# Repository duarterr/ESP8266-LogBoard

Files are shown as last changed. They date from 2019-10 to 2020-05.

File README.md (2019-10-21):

# ESP8266 LogBoard

A development platform for the ESP8266 with data logger capabilities. Fully compatible with the Arduino IDE.

<p align="center">
ESP8266 LogBoard
</p>

Author: Renan R. Duarte - <duarte.renan@hotmail.com>

## Features
 - **ESP8266 (ESP12E) microcontroller:** The board is based on the ESP12E module, featuring the ESP8266 microcontroller. The module is configured in DIO SPI mode, so two extras GPIO pins can be used by the application (13 GPIOs in total).
 - **MicroSD card:** Data can be easily stored in a standard microSD card.
 - **Temperature sensor:** The Maxim DS1722 SPI temperature sensor can be used to measure the temperature.
 - **Real-time clock:** A Maxim DS1391 battery-backed SPI real-time clock provides timing capabilities without needing the internet.
 - **Onboard battery charger:** The board can be powered directly from the USB port or by a lithium battery. The onboard battery charger can be configured to fully charge the battery (4.2V) for cyclic use or float charge with a lower voltage (4.1V) to extend battery life in applications where the USB power is always connected.
 - **Switched-mode power supply:** A Maxim MAX8625 buck-boost controller IC provides a high efficiency continuous 3.3V bus to the system.
 - **Onboard programmer:** The device can be programmed directly by the USB port using the onboard USB-Serial bridge (FTDI FT232RQ). This device also enables serial communications between the microcontroller and a PC.

## Repository Contents

* **/Hardware** - PCB related files (EAGLE v9.5.5 and Sketchup 2018).
* **/Firmware** - Arduino example sketches to make use of it. 
* **/Extras** - Images and other stuff. 

## License Information

All contents of this repository are released under [Creative Commons Share-alike 4.0](http://creativecommons.org/licenses/by-sa/4.0/).

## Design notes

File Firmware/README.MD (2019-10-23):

# Firmware

## Arduino/LogBoard
This is the main firmware of the LogBoard.

## Arduino/SD Card files
- **NewSettings_Example.txt:** At boot, the device checks if a "NewSettings.txt" file is present. If it is, all settings in EEPROM are replaced by the ones in this file. "NewSettings_Example.txt" is a template of the configuration file.
- **NewFirmware.bin:** At boot, the device checks if a "NewFirmware.bin" file is present. If it is, the firmware is updated.

## Google Script/GScriptCode.txt
This code gets the logged data via HTTP post and saves it to a Google Sheets document

## Google Script/HTTPsRedirect.php
This code receives the ESP8266 HTTP post requests and redirects the requests to via HTTPS. The URL of this script is the WifiRedirectURL in the Arduino code.

## Firmware Flowchart

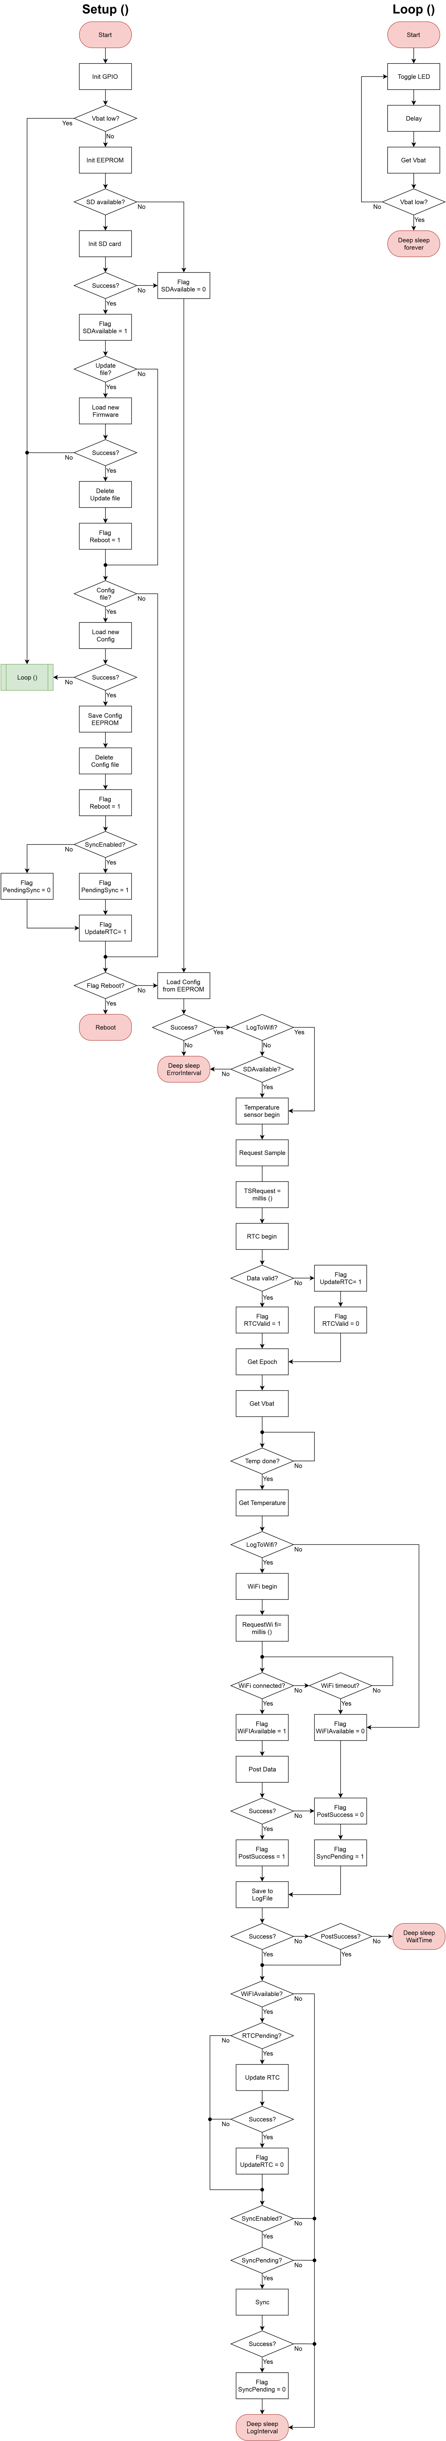
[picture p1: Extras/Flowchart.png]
v1


## License Information

All contents of this repository are released under [Creative Commons Share-alike 4.0](http://creativecommons.org/licenses/by-sa/4.0/).

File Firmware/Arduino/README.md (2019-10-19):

# Arduino sketches and related files

## LogBoard
This is the main firmware of the LogBoard.

## SD Card files
- **NewConfig_Example.txt:** At boot, the device checks if a "NewConfig.txt" file is present. If it is, all settings in EEPROM are replaced by the ones in this file. "NewConfig_Example.txt" is a template of the configuration file.
- **NewFirmware.bin:** At boot, the device checks if a "NewFirmware.bin" file is present. If it is, the firmware is updated.

## License Information

All contents of this repository are released under [Creative Commons Share-alike 4.0](http://creativecommons.org/licenses/by-sa/4.0/).

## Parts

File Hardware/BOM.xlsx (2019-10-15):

Part | Value | Description | Package
C1 | 100n/10V | 0603 SMD capacitor | 0603
C2 | 47u/6.3V | CT3528 SMD tantalum capacitor | CT3528
C3 | 47u/6.3V | CT3528 SMD tantalum capacitor | CT3528
C4 | 1u/10V | 0603 SMD capacitor | 0603
C5 | 1u/10V | 0603 SMD capacitor | 0603
C6 | 0.33F/5.5V - KR-5R5V334-R | Coin cell supercapacitor | PTH 5X11.5
C7 | 10u/10V | 0603 SMD capacitor | 0603
C8 | 100n/10V | 0603 SMD capacitor | 0603
C9 | 100n/10V | 0603 SMD capacitor | 0603
C10 | 100n/10V | 0603 SMD capacitor | 0603
C11 | 1u/10V | 0603 SMD capacitor | 0603
C12 | 100n/10V | 0603 SMD capacitor | 0603
C13 | 100n/10V | 0603 SMD capacitor | 0603
C14 | 100n/10V | 0603 SMD capacitor | 0603
C15 | 10u/10V | 0603 SMD capacitor | 0603
C16 | 100n/10V | 0603 SMD capacitor | 0603
FB1 | 15 | 0603 SMD ferrite bead | 0603
IC1 | ESP12E | ESP12E module | IC-ESP8266-12E
IC2 | FT232RQ | USB UART IC | QFN32
IC3 | MAX14591ETA+ | Logic level translator | TDFN8
IC4 | MAX14591ETA+ | Logic level translator | TDFN8
IC5 | MAX1811ESA+ | USB-Powered Li+ Charger | SO8
IC6 | MAX8625AETD+ | Step-Up/Down DC-DC Converter | TDFN14
IC7 | DS1391U-33+ | Low-Voltage SPI/3-Wire RTCs with Trickle Charger | USOP10
IC8 | DS1722S+ | Digital Thermometer with SPI/3-Wire Interface | SO8
J1 | C77238 | Micro USB 5P B SMD | Micro USB 5P B SMD
J2 | THD2528-11SD-GF | Micro SD card SMD connector | Micro SD card SMD connector
J3 | HEADER 2x9 180 | 09x2 0.1" pitch male header | 09x2 0.1" pitch male header
L1 | SRN3015-3R3M | 3x3mm SMD inductor | 3x3mm SMD inductor
LED1 | BLUE | 0603 SMD LED | 0603
LED2 | RED | 0603 SMD LED | 0603
LED3 | RED | 0603 SMD LED | 0603
LED4 | BLUE | 0603 SMD LED | 0603
Q1 | BC847BS-7-F | Dual NPN transistor | SOT363
R1 | 10k | 0603 SMD resistor | 0603
R2 | 0/WAKE | 0603 SMD resistor | 0603
R3 | 390k | 0603 SMD resistor | 0603
R4 | 100k | 0603 SMD resistor | 0603
R5 | 10k | 0603 SMD resistor | 0603
R6 | 10k | 0603 SMD resistor | 0603
R7 | 10k | 0603 SMD resistor | 0603
R8 | 10k | 0603 SMD resistor | 0603
R9 | 10k | 0603 SMD resistor | 0603
R10 | 33 | 0603 SMD resistor | 0603
R11 | 33 | 0603 SMD resistor | 0603
R12 | 1k | 0603 SMD resistor | 0603
R13 | 1k | 0603 SMD resistor | 0603
S1 | SK-3296S-01-L1 | Right angle SMD slide switch | Right angle SMD slide switch
S2 | TS24CA | Right angle SMD momentary switch | Right angle SMD momentary switch
X1 | SSP-T7-F 32.768kHz 20PPM7pF | 7015 SMD crystal oscillator | 7015 4P

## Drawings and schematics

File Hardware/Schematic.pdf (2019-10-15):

### ABCD

### ABCD

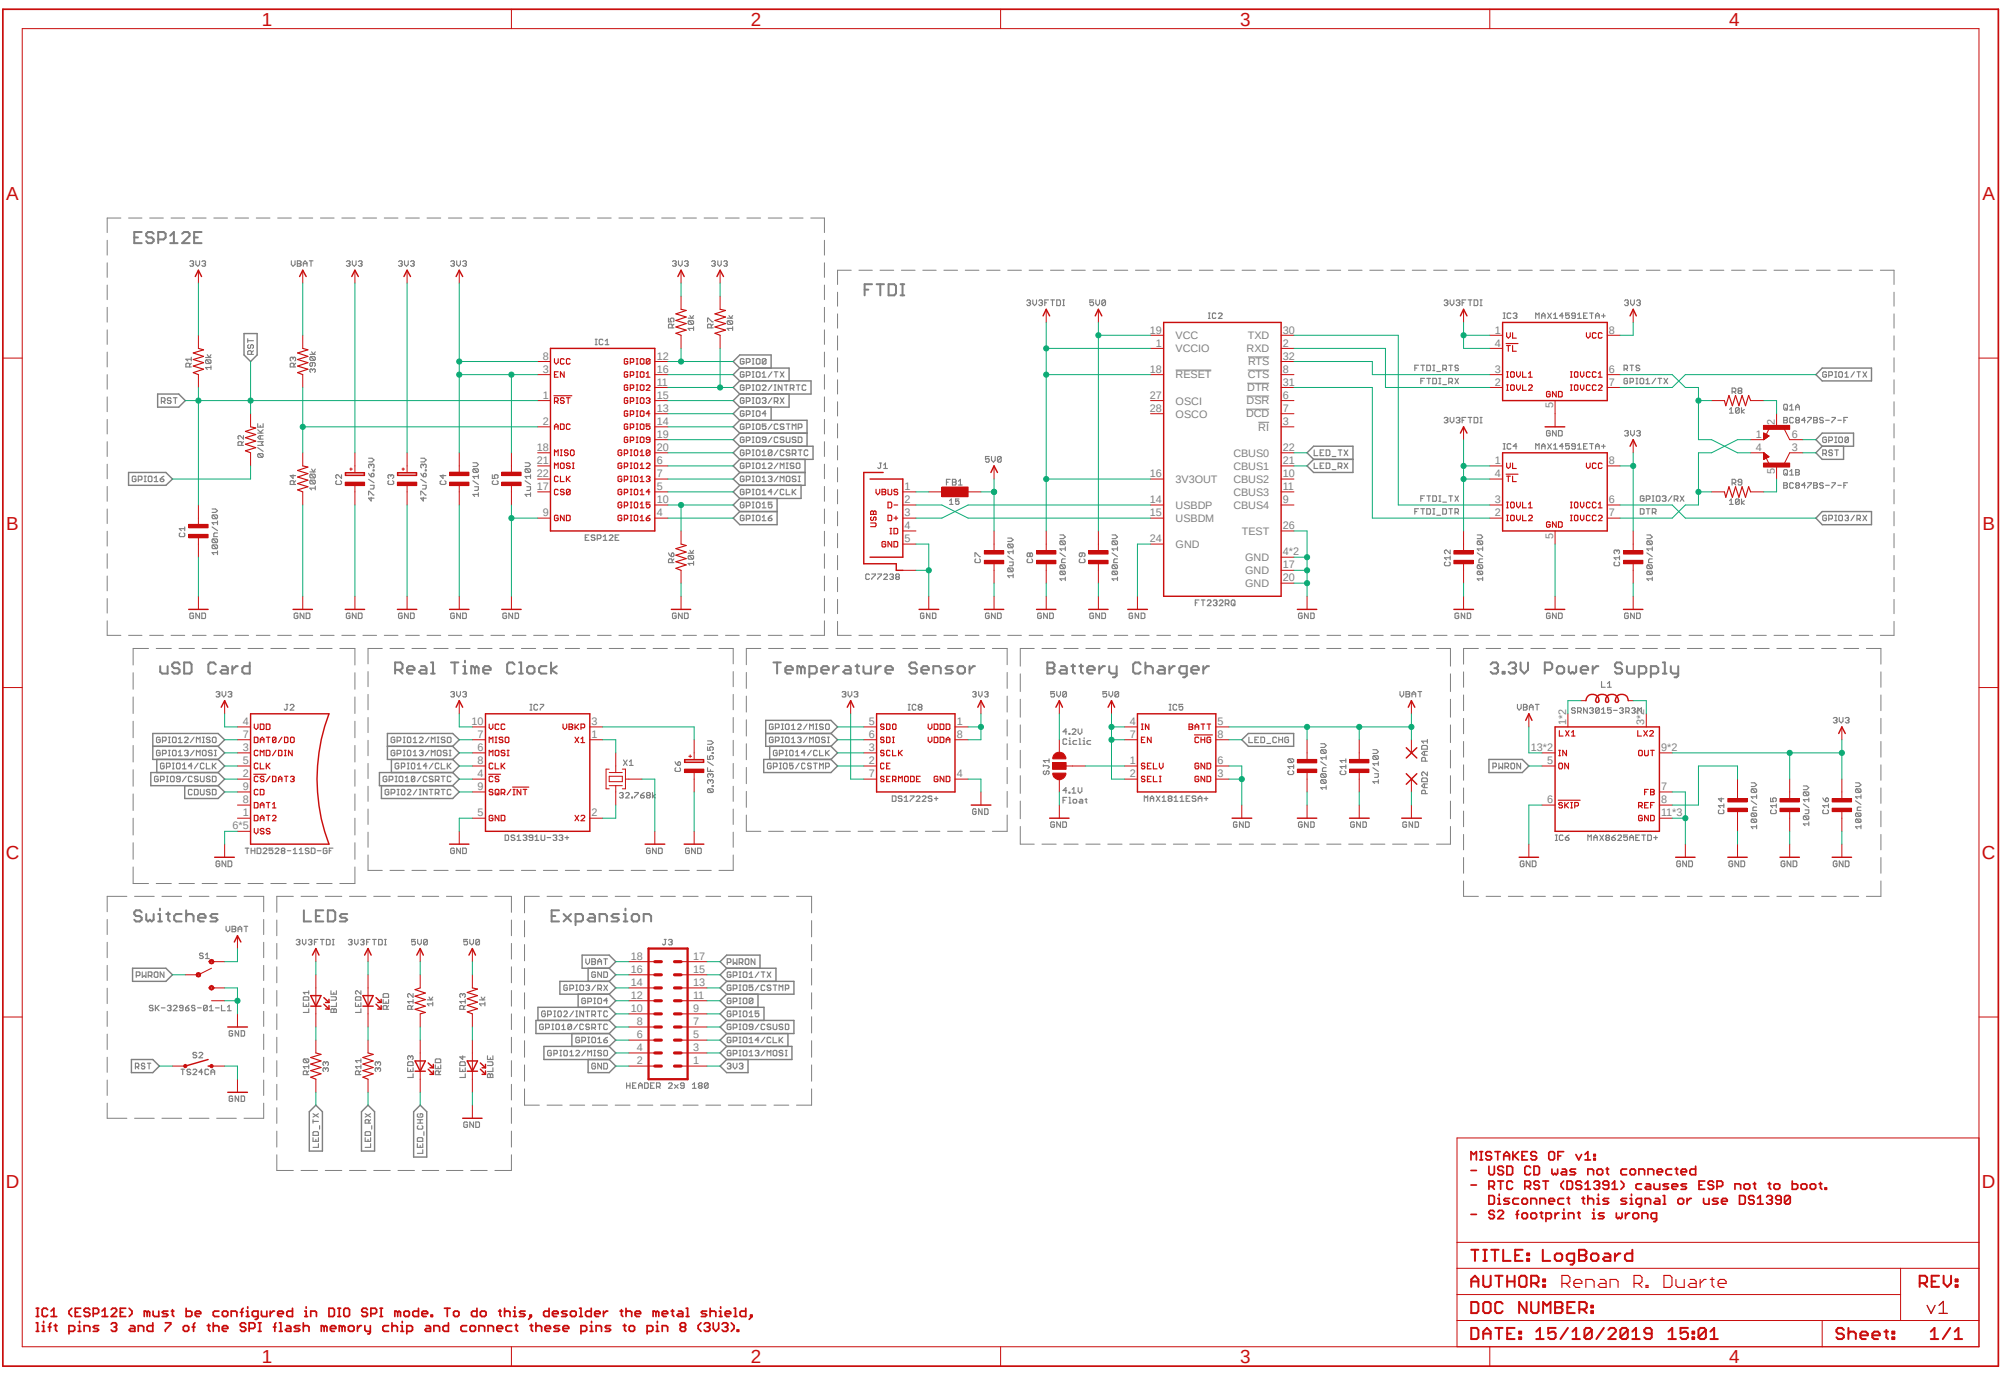
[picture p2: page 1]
CTS; DCD; 7 DSR; 6 DTR; 31 RESET 18; RTS; 3V3OUT 16; CBUS0; CBUS1; CBUS2; CBUS3; CBUS4; GND; GND 24; OSCI 27 OSCO 28; RXD; TEST; TXD; USBDM 15; USBDP 14; VCC 19; VCCIO

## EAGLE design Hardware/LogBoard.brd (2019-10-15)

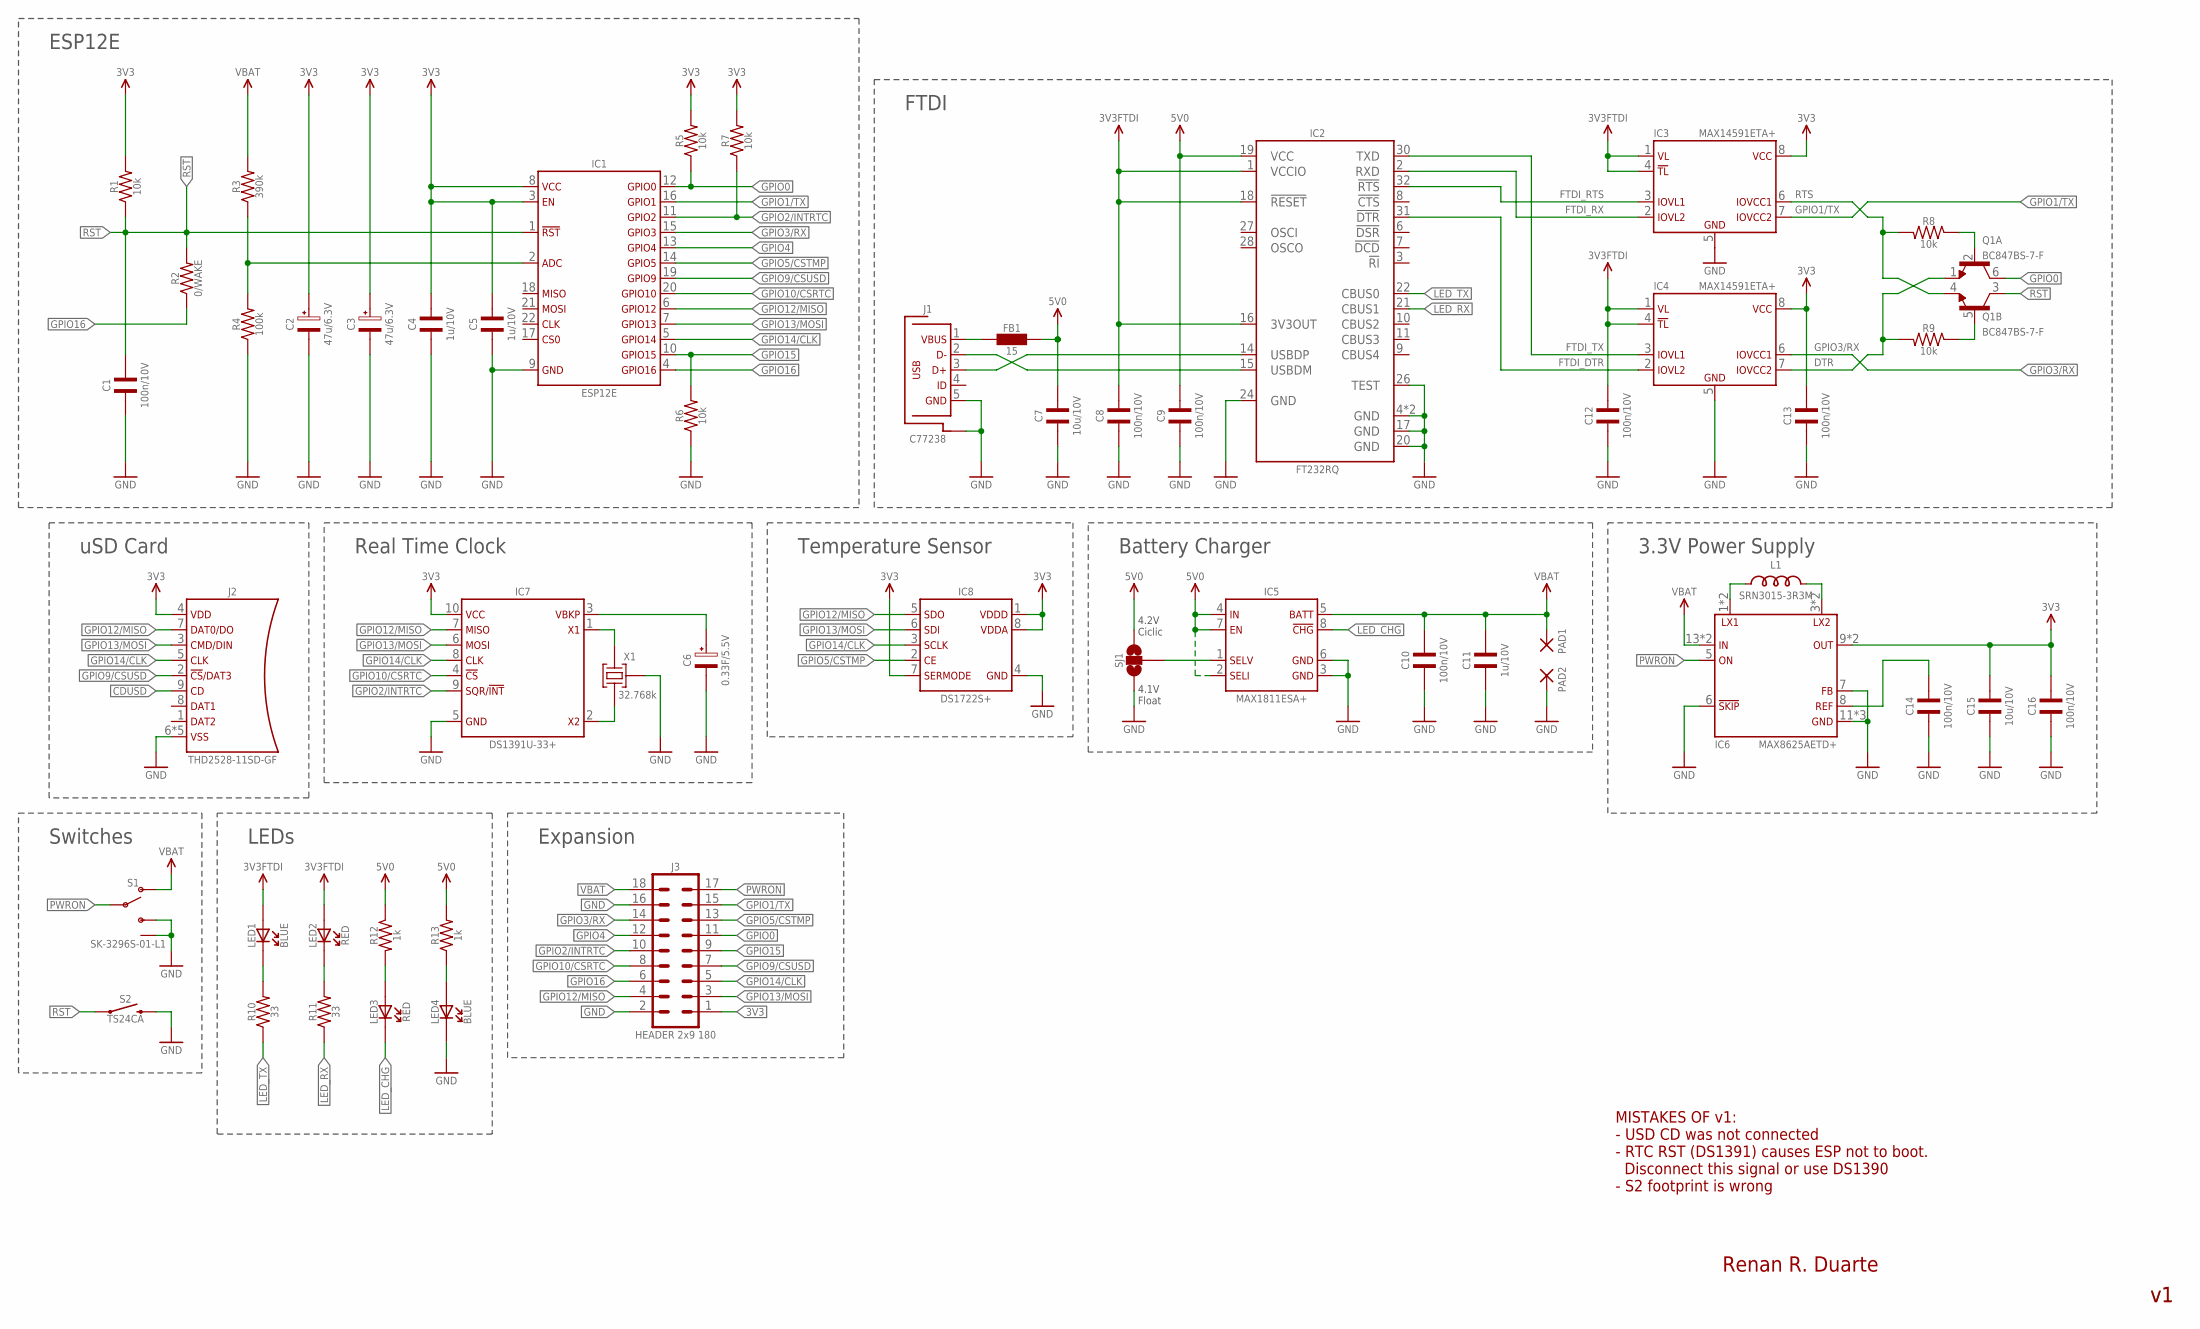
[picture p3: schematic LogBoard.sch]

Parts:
C1, C8, C9, C10, C12, C13, C14, C16: 100n/10V; C-SMD-0603
C2, C3: 47u/6.3V; C-SMD-CT3528
C4, C5, C11: 1u/10V; C-SMD-0603
C6: 0.33F/5.5V; C-PTH-5X11.5
C7, C15: 10u/10V; C-SMD-0603
FB1: 15; R-SMD-0603
IC1: ESP12E; IC-ESP8266-12E
IC2: FT232RQ; IC-QFN32
IC3, IC4: MAX14591ETA+; IC-TDFN8
IC5: MAX1811ESA+; IC-SO8
IC6: MAX8625AETD+; IC-TDFN14
IC7: DS1391U-33+; IC-USOP10
IC8: DS1722S+; IC-SO8
J1: C77238; CN-MICRO-USB
J2: THD2528-11SD-GF; CN-MICROSD
J3: HEADER 2x9 180; PH-9X2-180
L1: SRN3015-3R3M; L-SMD-3X3
LED1, LED4: BLUE; LED-SMD-0603
LED2, LED3: RED; LED-SMD-0603
PAD1, PAD2: SMD2; SMD1,27-2,54
Q1: BC847BS-7-F; IC-SOT363
R1, R5, R6, R7, R8, R9: 10k; R-SMD-0603
R2: 0/WAKE; R-SMD-0603
R3: 390k; R-SMD-0603
R4: 100k; R-SMD-0603
R10, R11: 33; R-SMD-0603
R12, R13: 1k; R-SMD-0603
S1: SK-3296S-01-L1; SWITCH_SPST_SMD_A
S2: TS24CA; TACTILE_SWITCH_SMD_RIGHT_ANGLE
SJ1: SJ-3
X1: 32.768k; CRYSTAL-SMD-7X1.5

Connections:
3V3: C2.+, C3.+, C4.P$1 (1), C5.P$1 (1), C13.P$2 (2), C15.P$1 (1), C16.P$1 (1), IC1.3 (EN), IC1.8 (VCC), IC3.8 (VCC), IC4.8 (VCC), IC6.9 (OUT), IC6.10 (OUT), IC7.10 (VCC), IC8.1 (VDDD), IC8.7 (SERMODE), IC8.8 (VDDA), J2.4 (VDD), J3.1, R1.P$2 (2), R5.P$2 (2), R7.P$2 (2)
3V3FTDI: C8.P$2 (2), C12.P$2 (2), IC2.1 (VCCIO), IC2.16 (3V3OUT), IC2.18 (!RESET), IC3.1 (VL), IC3.4 (!TL), IC4.1 (VL), IC4.4 (!TL), LED1.A, LED2.A
5V0: C7.P$2 (2), C9.P$2 (2), FB1.P$2 (2), IC2.19 (VCC), IC5.2 (SELI), IC5.4 (IN), IC5.7 (EN), R12.P$1 (1), R13.P$2 (2), SJ1.1
CDUSD: J2.9 (CD)
DTR: IC4.7 (IOVCC2), Q1.1 (E), R9.P$2 (2)
FTDI_DTR: IC2.31 (!DTR), IC4.2 (IOVL2)
FTDI_RTS: IC2.32 (!RTS), IC3.3 (IOVL1)
FTDI_RX: IC2.2 (RXD), IC3.2 (IOVL2)
FTDI_TX: IC2.30 (TXD), IC4.3 (IOVL1)
GND: C1.P$1 (1), C2.- (N), C3.- (N), C4.P$2 (2), C5.P$2 (2), C6.N, C7.P$1 (1), C8.P$1 (1), C9.P$1 (1), C10.P$2 (2), C11.P$2 (2), C12.P$1 (1), C13.P$1 (1), C14.P$2 (2), C15.P$2 (2), C16.P$2 (2), IC1.9 (GND), IC2.4 (GND), IC2.17 (GND), IC2.20 (GND), IC2.24 (GND), IC2.26 (TEST), IC2.GND, IC3.5 (GND), IC4.5 (GND), IC5.3 (GND), IC5.6 (GND), IC6.6 (!SKIP), IC6.7 (FB), IC6.11 (GND), IC6.12 (GND), IC6.TP (GND), IC7.5 (GND), IC8.4 (GND), J1.5 (GND), J1.SHELL (SHIELD), J1.SHELL1 (SHIELD), J1.SHELL2 (SHIELD), J1.SHELL3 (SHIELD), J2.6 (VSS), J2.G1 (VSS), J2.G2 (VSS), J2.G3 (VSS), J2.G4 (VSS), J3.2, J3.16, LED4.C, PAD2.1, R4.P$1 (1), R6.P$1 (1), S1.3 (S), S1.GND1, S1.GND2, S1.GND3, S1.GND4, S2.2, SJ1.3, X1.3 (2), X1.4 (2)
GPIO0: IC1.12 (GPIO0), J3.11, Q1.6 (C), R5.P$1 (1)
GPIO1/TX: IC1.16 (GPIO1), IC3.7 (IOVCC2), J3.15
GPIO2/INTRTC: IC1.11 (GPIO2), IC7.9 (INT), J3.10, R7.P$1 (1)
GPIO3/RX: IC1.15 (GPIO3), IC4.6 (IOVCC1), J3.14
GPIO4: IC1.13 (GPIO4), J3.12
GPIO5/CSTMP: IC1.14 (GPIO5), IC8.2 (CE), J3.13
GPIO9/CSUSD: IC1.19 (GPIO9), J2.2 (CD_DAT3_CS), J3.7
GPIO10/CSRTC: IC1.20 (GPIO10), IC7.4 (CS), J3.8
GPIO12/MISO: IC1.6 (GPIO12), IC7.7 (MISO), IC8.5 (SDO), J2.7 (DAT0_DO), J3.4
GPIO13/MOSI: IC1.7 (GPIO13), IC7.6 (MOSI), IC8.6 (SDI), J2.3 (CMD_DIN), J3.3
GPIO14/CLK: IC1.5 (GPIO14), IC7.8 (CLK), IC8.3 (SCLK), J2.5 (CLK), J3.5
GPIO15: IC1.10 (GPIO15), J3.9, R6.P$2 (2)
GPIO16: IC1.4 (GPIO16), J3.6, R2.P$1 (1)
LED_CHG: IC5.8 (!CHG), LED3.C
LED_RX: IC2.21 (CBUS1), R11.P$1 (1)
LED_TX: IC2.22 (CBUS0), R10.P$1 (1)
unnamed: Q1.2 (B), R8.P$1 (1)
unnamed: Q1.5 (B), R9.P$1 (1)
unnamed: FB1.P$1 (1), J1.1 (VBUS)
unnamed: IC2.15 (USBDM), J1.2 (D-)
unnamed: IC2.14 (USBDP), J1.3 (D+)
unnamed: LED1.C, R10.P$2 (2)
unnamed: LED2.C, R11.P$2 (2)
unnamed: LED3.A, R12.P$2 (2)
unnamed: IC5.1 (SELV), SJ1.2
unnamed: IC6.1 (LX1), IC6.2 (LX1), L1.P$1 (1)
unnamed: IC6.3 (LX2), IC6.4 (LX2), L1.P$2 (2)
unnamed: IC1.2 (ADC), R3.P$1 (1), R4.P$2 (2)
unnamed: IC7.1 (X1), X1.2 (3)
unnamed: IC7.2 (X2), X1.1
unnamed: C14.P$1 (1), IC6.8 (REF)
unnamed: LED4.A, R13.P$1 (1)
PWRON: IC6.5 (ON), J3.17, S1.2
RST: C1.P$2 (2), IC1.1 (RST), Q1.3 (C), R1.P$1 (1), R2.P$2 (2), S2.1
RTS: IC3.6 (IOVCC1), Q1.4 (E), R8.P$2 (2)
VBAT: C10.P$1 (1), C11.P$1 (1), IC5.5 (BATT), IC6.13 (IN), IC6.14 (IN), J3.18, PAD1.1, R3.P$2 (2), S1.1 (O)
VBKP: C6.P, IC7.3 (VBKP)

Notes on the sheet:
4.1V Float
4.2V Ciclic
FTDI
Battery Charger
3.3V Power Supply
ESP12E
Expansion
uSD Card
Real Time Clock
LEDs
Switches
Temperature Sensor
MISTAKES OF v1: - USD CD was not connected - RTC RST (DS1391) causes ESP not to boot. Disconnect this signal or use DS1390 - S2 footprint is wrong
Renan R. Duarte

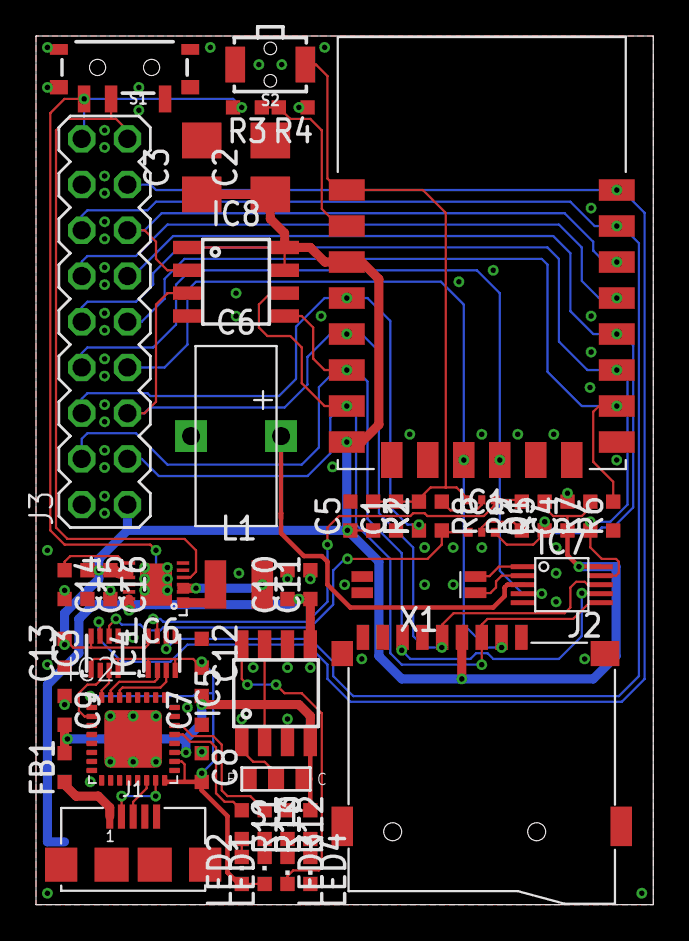
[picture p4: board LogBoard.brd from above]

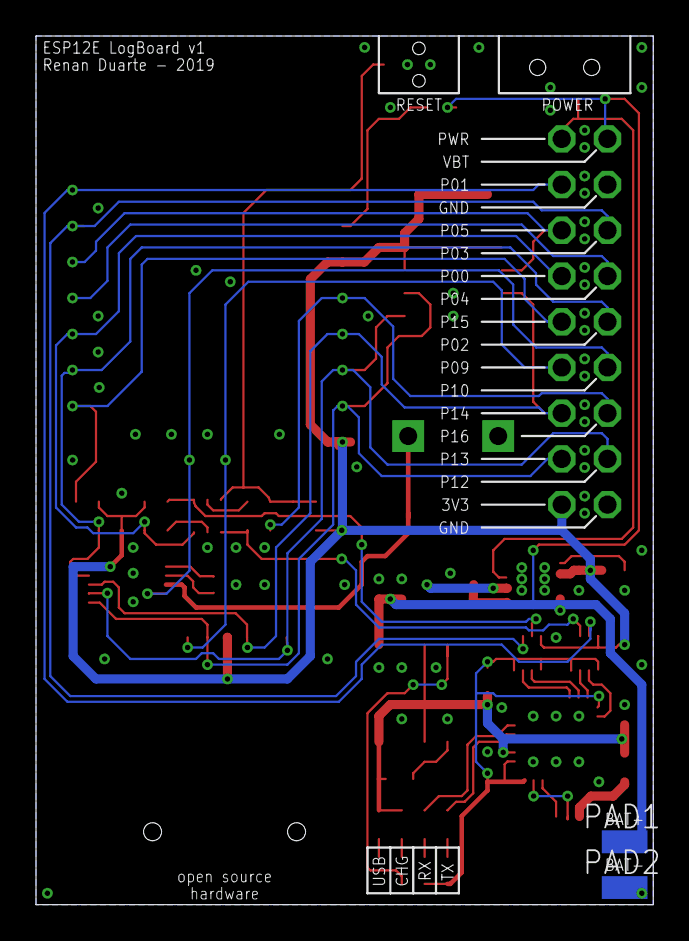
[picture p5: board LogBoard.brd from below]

Board: 2 copper layers, 34.3 x 48.3 mm, 54 parts (3 on the bottom side), 46 nets.

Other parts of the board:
U$7: OSHW_5MM

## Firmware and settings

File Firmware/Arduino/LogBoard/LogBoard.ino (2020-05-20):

/* ------------------------------------------------------------------------------------------- */
// LogBoard - Data logger firwmare for the ESP8266 LogBoard
// Version: 1.2
// Author:  Renan R. Duarte
// E-mail:  duarte.renan@hotmail.com
// Date:    May 19, 2020
//
// Notes:   Sending data to Google Sheets (via Google Script) could be done directly using the
//          WiFiClientSecure library. However, HTTPS requests require more heap memory than
//          the device has available in this code when the HTTPS connection is made.
//          As a solution, this code sends an HTTP request to a server where a HTTPs redirect
//          is performed using cURL.
//
// TODO: 	If log file is large, sync may take a lot of time. Must find a way to keep
//          track of where to start the sync.
//			
//
// Released into the public domain
/* ------------------------------------------------------------------------------------------- */

/* ------------------------------------------------------------------------------------------- */
// Libraries
/* ------------------------------------------------------------------------------------------- */

// DS1722 SPI thermometer related functions
#include <DS1722_SPI.h> // https://github.com/duarterr/Arduino-DS1722-SPI

// DS1390 SPI real time clock related functions
#include <DS1390_SPI.h> // https://github.com/duarterr/Arduino-DS1390-SPI

// ESP8266 WiFi related functions
#include <ESP8266WiFi.h>

// ESP8266 HTTP client related functions
#include <ESP8266HTTPClient.h>

// ESP8266 UDP related functions
#include <WiFiUdp.h>

// NTP client related functions
#include <NTPClient.h>

// EEPROM module related functions
#include <EEPROM.h>

// SD card related functions
#include <SdFat.h>
using namespace sdfat;

// BME280 related functions
#include <Adafruit_Sensor.h>
#include <Adafruit_BME280.h>

/* ------------------------------------------------------------------------------------------- */
// Hardware defines
/* ------------------------------------------------------------------------------------------- */

// Peripheral pins
#define PIN_SD_CS               9
#define PIN_SD_CD               4
#define PIN_RTC_CS              10
#define PIN_TS_CS               5
#define PIN_BME_CS              15
#define PIN_LED                 2
#define PIN_ADC                 A0

// ADC gain
#define ADC_GAIN                0.005343342

/* ------------------------------------------------------------------------------------------- */
// Software default constants
/* ------------------------------------------------------------------------------------------- */

// Default settings filename
const PROGMEM char* FilenameNewSettings = "NewSettings.txt";

// Default firmware filename
const PROGMEM char* FilenameNewFirmware = "NewFirmware.bin";

// NTP server - Result is given by server closest to you, so it's usually in your timezone
const PROGMEM char* NTPServerURL = "0.br.pool.ntp.org";  // Brazilian server

/* ------------------------------------------------------------------------------------------- */
// Software defines
/* ------------------------------------------------------------------------------------------- */

// Code debug with serial port
#define DEBUG_SERIAL            true

// Time to sleep if an error occur loading settings from EEPROM (seconds)
#define ERROR_SLEEP_INTERVAL    60

// WiFi connection timeout (milliseconds)
#define WIFI_TIMEOUT            5000

// Battery voltage cutoff voltage (volts)
#define VBAT_LOW                3

// EEPROM addresses
#define ADDR_LOG_FILENAME       0x000 // 64 bytes (63c + '\n')
#define ADDR_LOG_INTERVAL       0x040 // 2 bytes (MSB + LSB)
#define ADDR_LOG_WAIT_TIME      0x042 // 2 bytes (MSB + LSB) 
#define ADDR_LOG_TIMEZONE       0x044 // 2 bytes (MSB + LSB)
#define ADDR_WIFI_ENABLED       0x046 // 1 byte
#define ADDR_WIFI_SYNC          0x047 // 1 byte
#define ADDR_WIFI_SSID          0x048 // 32 bytes (31c + '\n')
#define ADDR_WIFI_PSW           0x068 // 32 bytes (31c + '\n')
#define ADDR_WIFI_REDIRECTURL   0x088 // 64 bytes (63c + '\n')
#define ADDR_WIFI_GSCRIPTURL    0x0C8 // 128 bytes (127c + '\n')
#define ADDR_CHECKSUM           0x148 // 4 bytes
#define ADDR_RTC_PENDING        0x14C // 1 byte
#define ADDR_SYNC_PENDING       0x14D // 1 byte

// EEPROM total bytes
#define EEPROM_SIZE             0x14E // 334 bytes

/* ------------------------------------------------------------------------------------------- */
// Global variables
/* ------------------------------------------------------------------------------------------- */

// Configuration variables
struct StructSettings
{
  char LogFilename[64] = {0};         // SD card log file       
  unsigned int LogInterval = 1;       // Time between samples (10 to 3600 seconds)
  unsigned int LogWaitTime = 1;       // Time to wait after on error (1 to 3600 seconds)
  int LogTimezone = 0;                // Timezone (-12 to +12, 0 = GMT)
  unsigned char WifiEnabled = 0;      // Use WiFi functions
  unsigned char WifiSyncEnable = 0;   // Sync data stored in SD card to Google Sheets
  char WifiSSID[32] = {0};            // WiFi SSID
  char WifiPsw[32] = {0};             // WiFi password
  char WifiRedirectURL[64] = {0};     // URL of the HTTP->HTTPs redirect host
  char WifiGScriptURL[128] = {0};     // Google Script ID
} Settings, NewSettings;

// Sampled data
struct StructSample
{
  unsigned char DeviceMAC[6] = {};    // Device MAC address
  float Temperature = 0;              // DS1722 temperature
  float BatteryVoltage = 0;           // ADC voltage
  unsigned long RTCEpoch = 0;         // RTC date and time - Epoch format
  bool RTCValid = false;              // RTC memory was not lost. Data is reliable
  bool BmeStatus = false;             // BME280 status
  float BmeTemperature = 0;           // BME280 temperature
  float BmePressure = 0;              // BME280 pressure
  float BmeHumidity = 0;              // BME280 humidity
} Sample;

// Code flags
struct StructFlag
{
  bool SDAvailable = false;           // SD is installed and accessible
  bool WifiAvailable = false;         // WiFi is connected
  bool NewFirmwareSuccess = false;    // New firmware was correctly loaded
  bool NewSettingsSuccess = false;    // New congiguration was correctly loaded
  bool SaveWifiSuccess = false;       // Sample was posted to Google Sheets
  bool SaveSDSuccess = false;         // Sample was saved in SD card
  bool PendingReboot = false;         // Reboot is pending
  bool PendingRTCUpdate = false;      // RTC update is pending
  bool PendingWifiSync = false;       // WiFi sync is pending
} Flag;

// Code times
struct StructTime
{
  unsigned int RequestTS = 0;         // Temperature conversion request time
  unsigned int RequestWifi = 0;       // WiFi connection request time
} Time;

// Log buffer
char Buffer[256] = {0};

// HTTP post response code
short PostResponseCode = 0;

// HTTP post response - Expected only "-1", "0" or "1"
char PostResponseString[2] = {0};

/* ------------------------------------------------------------------------------------------- */
// Constructors
/* ------------------------------------------------------------------------------------------- */

// Temperature sensor
DS1722 TS (PIN_TS_CS);

// Real time clock
DS1390 RTC (PIN_RTC_CS);

// SD card
SdFat SDCard;

// New settings file
File FileNewSettings;

// New firmware file
File FileNewFirmware;

// Log file
File FileLog;

// HTTP client
HTTPClient LogClient;

// UDP
WiFiUDP UDP;

// NTP client
NTPClient NTP(UDP, NTPServerURL);

// BME280 - SPI mode
Adafruit_BME280 Bme280 (PIN_BME_CS);

/* ------------------------------------------------------------------------------------------- */
// Name:        setup
// Description: This function runs on boot
// Arguments:   None
// Returns:     None
/* ------------------------------------------------------------------------------------------- */

void setup()
{
  /* ----------------------------------------------------------------------------------------- */
  // Init Serial
  /* ----------------------------------------------------------------------------------------- */
  
  #if DEBUG_SERIAL
  Serial.begin(74880);
  while (!Serial);
  #endif

  /* ----------------------------------------------------------------------------------------- */
  // Init GPIO
  /* ----------------------------------------------------------------------------------------- */

  #if DEBUG_SERIAL
  Serial.printf ("[%05d] Initializing GPIOs... \n", millis());
  #endif
    
  // Set LED pin as digital output
  pinMode(PIN_LED, OUTPUT);

  // LED off
  digitalWrite (PIN_LED, HIGH);

  // Set Card Detect pin as input with pullup
  pinMode(PIN_SD_CD, INPUT_PULLUP);  

  // Set BME280 CS pin as digital output - Pin must be high before SD init to avoid interference
  pinMode(PIN_BME_CS, OUTPUT);

  // BME280 off
  digitalWrite (PIN_BME_CS, HIGH);

  #if DEBUG_SERIAL
  Serial.printf ("[%05d] Done. \n", millis());  
  #endif  

  /* ----------------------------------------------------------------------------------------- */
  // Check Vbat
  /* ----------------------------------------------------------------------------------------- */  

  #if DEBUG_SERIAL
  Serial.printf ("[%05d] Checking battery voltage... \n", millis());
  #endif
  
   // Get battery voltage
  Sample.BatteryVoltage = analogRead(PIN_ADC) * ADC_GAIN; 

  // Jump to loop if battery voltage is too low
  if (Sample.BatteryVoltage < VBAT_LOW)
    return;

  #if DEBUG_SERIAL
  Serial.printf ("[%05d] Done. \n", millis());  
  #endif     

  /* ----------------------------------------------------------------------------------------- */
  // Get ESP8266 MAC address
  /* ----------------------------------------------------------------------------------------- */  

  // Save device MAC
  WiFi.macAddress(Sample.DeviceMAC);
  
  #if DEBUG_SERIAL
  Serial.printf ("[%05d] Device MAC addess: %02X:%02X:%02X:%02X:%02X:%02X \n", millis(), 
    Sample.DeviceMAC[5], Sample.DeviceMAC[4], Sample.DeviceMAC[3], 
    Sample.DeviceMAC[2], Sample.DeviceMAC[1], Sample.DeviceMAC[0]); 
  #endif  
  
  /* ----------------------------------------------------------------------------------------- */
  // Init EEPROM
  /* ----------------------------------------------------------------------------------------- */
  
  #if DEBUG_SERIAL
  Serial.printf ("[%05d] Initializing EEPROM... \n", millis());  
  #endif

  // Init EEPROM
  EEPROM.begin (EEPROM_SIZE);

  #if DEBUG_SERIAL
  Serial.printf ("[%05d] Done. \n", millis());  
  #endif

  /* ----------------------------------------------------------------------------------------- */
  // Init SD card
  /* ----------------------------------------------------------------------------------------- */

  #if DEBUG_SERIAL
  Serial.printf ("[%05d] Checking SD card... \n", millis());  
  #endif
    
  // SD card was detected
  if (!digitalRead (PIN_SD_CD))
  {
    #if DEBUG_SERIAL
    Serial.printf ("[%05d] SD card detected. \n", millis()); 
    #endif   

    // Initialize SD card
    if (SDCard.begin(PIN_SD_CS))
    {
      // Set flag
      Flag.SDAvailable = true;  

      #if DEBUG_SERIAL
      Serial.printf ("[%05d] Card initialized. Size: %d MB. \n", millis(), SDCard.card()->cardSize()/2048);   
      #endif
    }

    // Fails to initialize SD card
    else
    {
      // Clear flag
      Flag.SDAvailable = false; 

      #if DEBUG_SERIAL
      Serial.printf ("[%05d] Error initializing SD card! \n", millis());
      #endif                
    }
  }
  
  // SD card was not detected
  else
  {
    // Clear flags
    Flag.SDAvailable = false;
    Flag.SaveSDSuccess = false;
    
    #if DEBUG_SERIAL
    Serial.printf ("[%05d] SD card not detected! \n", millis());
    #endif
  }

  /* ----------------------------------------------------------------------------------------- */
  // Firmware update
  /* ----------------------------------------------------------------------------------------- */  

  // SD card is was initialized
  if (Flag.SDAvailable)
  {
     // Try to open new firmware file
    FileNewFirmware = SDCard.open (FilenameNewFirmware, FILE_READ);   

    // Firmware file was found and opened
    if (FileNewFirmware)
    {
      // LED on
      digitalWrite (PIN_LED, LOW);    
      
      #if DEBUG_SERIAL
      Serial.printf ("[%05d] New firmware file detected. Updating... \n", millis());
      #endif  

      // Start update with max available SketchSpace
      if (Update.begin(((ESP.getFreeSketchSpace() - 0x1000) & 0xFFFFF000), U_FLASH))
      {
        // Read all bytes        
        while (FileNewFirmware.available())
        {
          unsigned char Buffer[128];
          FileNewFirmware.read((unsigned char *)Buffer, 128);
          Update.write(Buffer, sizeof(Buffer));
        }
      }   
      
      // Update failed to start with max available SketchSpace
      else
      {
        #if DEBUG_SERIAL
        Serial.printf ("[%05d] Invalid firmware file! \n", millis());
        #endif

        // Jump to loop
        return;
      }

      // Check if update was successful
      Flag.NewFirmwareSuccess = Update.end (true);      

      // Close the firmware file
      FileNewFirmware.close();
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
void loop ()
{
  // Toggle LED
  digitalWrite(PIN_LED, !digitalRead(PIN_LED));

  // Delay
  delay (250);

  // Get battery voltage
  Sample.BatteryVoltage = analogRead(PIN_ADC) * ADC_GAIN; 
  
  // Enter deep sleep forever if voltage is too low
  if (Sample.BatteryVoltage < VBAT_LOW)
  {
    #if DEBUG_SERIAL
    Serial.printf ("[%05d] Low battery! Shuting down... \n", millis());
    #endif     

    ESP.deepSleep(0, WAKE_RF_DEFAULT);
  }
}

/* ------------------------------------------------------------------------------------------- */
// Name:        getRTCPending
// Description: Gets the RTCPending flag value from EEPROM
// Arguments:   None
// Returns:     Flag value
/* ------------------------------------------------------------------------------------------- */

bool getRTCPending ()
{
  // Read byte and return
  return EEPROM.read (ADDR_RTC_PENDING);
}

/* ------------------------------------------------------------------------------------------- */
// Name:        setRTCPending
// Description: Writes the RTCPending flag value in EEPROM
// Arguments:   Flag value
// Returns:     None
/* ------------------------------------------------------------------------------------------- */

void setRTCPending (bool Value)
{
  // Write value
  EEPROM.write (ADDR_RTC_PENDING, Value);

  // Apply changes in EEPROM
  EEPROM.commit();
}

/* ------------------------------------------------------------------------------------------- */
// Name:        getSyncPending
// Description: Gets the WifiSyncPending flag value from EEPROM
// Arguments:   None
// Returns:     Flag value
/* ------------------------------------------------------------------------------------------- */

bool getSyncPending ()
{
  // Read byte and return
  return EEPROM.read (ADDR_SYNC_PENDING);
}

/* ------------------------------------------------------------------------------------------- */
// Name:        setSyncPending
// Description: Writes the WifiSyncPending flag value in EEPROM
// Arguments:   Flag value
// Returns:     None
/* ------------------------------------------------------------------------------------------- */

void setSyncPending (bool Value)
{
  // Write value
  EEPROM.write (ADDR_SYNC_PENDING, Value);

  // Apply changes in EEPROM
  EEPROM.commit();
}

/* ------------------------------------------------------------------------------------------- */
// Name:        getSettingsSD
// Description: Gets all the settings from SD card (FilenameNewSettings)
// Arguments:   Buffer - Pointer to the buffer struct
// Returns:     true if all parameters were parsed and false otherwise
/* ------------------------------------------------------------------------------------------- */

bool getSettingsSD (StructSettings &Buffer)
{
  // Line buffer
  char BufferLine[128];

  // End of line index position
  unsigned char EOLPos = 0;

  // Checksum - 10 parameters are expected. Set 1 bit of Checksum for each
  unsigned int NewSettingsChecksum = 0;

  // At this point, FileNewSettings is already open. Read all lines of file sequentially
  while ((EOLPos = FileNewSettings.fgets(BufferLine, sizeof(BufferLine))) > 0)
  {
    // Proccess only lines that contain variables
    if (BufferLine[0] == '$')
    {
      // Current line is $LogFilename
      if (strstr (BufferLine, "$LogFilename "))
      {
        // Start index to extract text
        unsigned char StartPos = 13;

        // Copy value to new settings buffer from StartPos to '\n'
        strncpy (Buffer.LogFilename, (BufferLine + StartPos), (EOLPos - StartPos - 1));

        // Increment checksum
        NewSettingsChecksum += 0x001;
      }

      // Current line is $LogInterval
      else if (strstr (BufferLine, "$LogInterval "))
      {
        // Start index to extract text
        unsigned char StartPos = 12;

        // Buffer
        char Value[5] = {0};

        // Copy value to buffer from StartPos to '\n'
        strncpy (Value, (BufferLine + StartPos), (EOLPos - StartPos - 1));

        // Convert value to number
        Buffer.LogInterval = atoi(Value);

        // Increment checksum if value is whithin limits
        if ((Buffer.LogInterval >= 10) && (Buffer.LogInterval <= 3600))
          NewSettingsChecksum += 0x002;        
      }

      // Current line is $LogWaitTime
      else if (strstr (BufferLine, "$LogWaitTime "))
      {
        // Start index to extract text
        unsigned char StartPos = 12;

        // Buffer
        char Value[5] = {0};

        // Copy value to buffer from StartPos to '\n'
        strncpy (Value, (BufferLine + StartPos), (EOLPos - StartPos - 1));

        // Convert value to number
        Buffer.LogWaitTime = atoi(Value);

        // // Increment checksum if value is whithin limits
        if ((Buffer.LogWaitTime >= 1) && (Buffer.LogWaitTime <= 3600))          
          NewSettingsChecksum += 0x004;        
      }

      // Current line is $LogTimezone
      else if (strstr (BufferLine, "$LogTimezone "))
      {
        // Start index to extract text
        unsigned char StartPos = 13;

        // Buffer
        char Value[4] = {0};

        // Copy value to buffer from StartPos to '\n'
        strncpy (Value, (BufferLine + StartPos), (EOLPos - StartPos - 1));

        // Convert value to number
        Buffer.LogTimezone = atoi(Value);

        // Increment checksum if value is whithin limits
        if ((Buffer.LogTimezone >= -12) && (Buffer.LogTimezone <= 12))
          NewSettingsChecksum += 0x008;          
      }

      // Current line is $WifiEnabled
      else if (strstr (BufferLine, "$WifiEnabled "))
      {
        // Start index to extract text
        unsigned char StartPos = 13;

        // Buffer
        char Value[2] = {0};

        // Copy value to buffer from StartPos to '\n'
        strncpy (Value, (BufferLine + StartPos), (EOLPos - StartPos - 1));

        // Convert value to number
        Buffer.WifiEnabled = atoi(Value);

        // Increment checksum if value is whithin limits
        if ((Buffer.WifiEnabled == 0) || (Buffer.WifiEnabled == 1))
          NewSettingsChecksum += 0x010;          
      }

      // Current line is $WifiSyncEnable
      else if (strstr (BufferLine, "$WifiSyncEnable "))
      {
        // Start index to extract text
        unsigned char StartPos = 16;

        // Buffer
        char Value[2] = {0};

        // Copy value to buffer from StartPos to '\n'
        strncpy (Value, (BufferLine + StartPos), (EOLPos - StartPos - 1));

        // Convert value to number
        Buffer.WifiSyncEnable = atoi(Value);

        // Increment checksum if value is whithin limits
        if ((Buffer.WifiSyncEnable == 0) || (Buffer.WifiSyncEnable == 1))
          NewSettingsChecksum += 0x020;          
      }

      // Current line is $WifiSSID
      else if (strstr (BufferLine, "$WifiSSID "))
      {
        // Start index to extract text
        unsigned char StartPos = 10;

        // Copy value to buffer from StartPos to '\n'
        strncpy (Buffer.WifiSSID, (BufferLine + StartPos), (EOLPos - StartPos - 1));

        // Increment checksum
        NewSettingsChecksum += 0x040;        
      }

      // Current line is $WifiPsw
      else if (strstr (BufferLine, "$WifiPsw "))
      {
        // Start index to extract text
        unsigned char StartPos = 9;

        // Copy value to buffer from StartPos to '\n'
        strncpy (Buffer.WifiPsw, (BufferLine + StartPos), (EOLPos - StartPos - 1));

        // Increment checksum
        NewSettingsChecksum += 0x080;        
      }

      // Current line is $WifiRedirectURL
      else if (strstr (BufferLine, "$WifiRedirectURL "))
      {
        // Start index to extract text
        unsigned char StartPos = 17;

        // Copy value to buffer from StartPos to '\n'
        strncpy (Buffer.WifiRedirectURL, (BufferLine + StartPos), (EOLPos - StartPos - 1));

        // Increment checksum
        NewSettingsChecksum += 0x100;           
      }

      // Current line is $WifiGScriptURL
      else if (strstr (BufferLine, "$WifiGScriptURL "))
      {
        // Start index to extract text
        unsigned char StartPos = 16;

        // Copy value to buffer from StartPos to '\n'
        strncpy (Buffer.WifiGScriptURL, (BufferLine + StartPos), (EOLPos - StartPos - 1));

        // Increment checksum
        NewSettingsChecksum += 0x200;          
      }
    }
  }

  // Return true if all parameters were parsed
  if (NewSettingsChecksum == 0x3FF)
    return true;
  else
    return false;
}
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

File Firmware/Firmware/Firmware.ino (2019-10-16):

/* ------------------------------------------------------------------------------------------- */
// Logger - Data logger
// Author:  Renan R. Duarte
// E-mail:  duarte.renan@hotmail.com
// Date:    October 14, 2019
//
// Notes:   Sending data to Google Sheets (via Google Script) can be done directly using the
//          WiFiClientSecure library. However, HTTPS requests require more heap memory than
//          the device has available in this code when the HTTPS connection is made.
//          As a solution, this code sends an HTTP request to a server where a HTTPs redirect
//          is performed using cURL.
//
// Released into the public domain
/* ------------------------------------------------------------------------------------------- */
//
// Code workflow: 
// (1) Init
// (2) Check for SD card -  N: Only Wifi, load last config from EEPROM
//                          Y: Check for new config file -  N: Load last from EEPROM
//                                                          Y: Save to EEPROM, delete config file
// (3) Start wifi connection                                                  
// (4) Start peripherals
// (5) Sample data
// (6) Check wifi connection -  Y: Post data - Get result
//                              N: Save to SD card if present
// (7) Check Vbat -   Normal: Sleep TIME_SAMPLE                          
//                    Low: Sleep forever
/* ------------------------------------------------------------------------------------------- */

/* ------------------------------------------------------------------------------------------- */
// Libraries
/* ------------------------------------------------------------------------------------------- */

// DS1722 SPI thermometer related functions
#include <DS1722_SPI.h> // https://github.com/duarterr/Arduino-DS1722-SPI

// DS1390 SPI real time clock related functions
#include <DS1390_SPI.h> // https://github.com/duarterr/Arduino-DS1390-SPI

// ESP8266 WiFi related functions
#include <ESP8266WiFi.h>

// ESP8266 HTTP client related functions
#include <ESP8266HTTPClient.h>

// EEPROM module related functions
#include <EEPROM.h>

// SD card related functions
#include <SdFat.h>
using namespace sdfat;

/* ------------------------------------------------------------------------------------------- */
// Hardware defines
/* ------------------------------------------------------------------------------------------- */

// Peripheral pins
#define PIN_SD_CS               9
#define PIN_SD_CD               4
#define PIN_RTC_CS              10
#define PIN_TS_CS               5
#define PIN_LED                 2
#define PIN_ADC                 A0

// ADC gain
#define ADC_GAIN                0.005311198

/* ------------------------------------------------------------------------------------------- */
// Software defines
/* ------------------------------------------------------------------------------------------- */

// Code debug with serial port
#define DEBUG_SERIAL            true

// WiFi connection timeout (seconds)
#define WIFI_TIMEOUT            5

// EEPROM addresses
#define ADDR_FILENAME           0                     // 64 bytes max (+ '\n')
#define ADDR_HOSTURL            ADDR_FILENAME + 64    // 64 bytes max (+ '\n')
#define ADDR_SCRIPTID           ADDR_HOSTURL + 64     // 64 bytes max (+ '\n')
#define ADDR_TIMEZONE           ADDR_SCRIPTID + 64    // 2 bytes max
#define ADDR_WIFI_SSID          ADDR_TIMEZONE + 2     // 32 bytes max (+ '\n')
#define ADDR_WIFI_PSW           ADDR_WIFI_SSID + 32   // 32 bytes max (+ '\n')
#define ADDR_TIME_SAMPLE        ADDR_WIFI_PSW + 32    // 2 bytes max 
#define ADDR_TIME_ERROR         ADDR_TIME_SAMPLE + 2  // 2 bytes max 

/* ------------------------------------------------------------------------------------------- */
// Constructors
/* ------------------------------------------------------------------------------------------- */

// Temperature sensor
DS1722 TS (PIN_TS_CS);

// Real time clock
DS1390 RTC (PIN_RTC_CS);

// SD card
SdFat SD;

// Configuration file
File ConfigFile;

// Log file
File LogFile;
    
// HTTP client
HTTPClient LogClient;

/* ------------------------------------------------------------------------------------------- */
// Global variables
/* ------------------------------------------------------------------------------------------- */

// Configuration file
const PROGMEM char* ConfigFilename = "NewConfig.csv";

// Configuration variables structure
struct StructConfig
{
  // Log file
  char Filename[64] = {0};
      
  // Wifi settings
  char WifiSSID[32] = {0};
  char WifiPsw[32] = {0};
  
  // Google script settings
  char HostURL[64] = {0};
  char ScriptID[64] = {0};
  
  // Time between samples (seconds) - Max 65535
  unsigned short SampleInterval = 0;
  
  // Deep sleep time if error (seconds) - Max 65535
  unsigned short ErrorInterval = 0;
  
  // Timezone (-12 to +12, 0 = GMT)
  int Timezone = 0;
} LogConfig;
   
// DS1722 temperature
float SensorTemperature = 0;

// ADC voltage
float BatteryVoltage = 0;

// Date and time - Epoch format
unsigned long EpochTime = 0;

// RTC data valid flag
bool RTCDataValid = false;
  
// Log flags
bool LogToSD = false;
bool LogToWifi = false;

// Log success flags
bool LogSDSuccess = false;
bool LogWifiSuccess = false;

// WiFi connection counter
unsigned char ConnectionCounter = 0;

// Log string
char Buffer[200] = {0};

/* ------------------------------------------------------------------------------------------- */
// Name:        setup
// Description: This function runs on boot
// Arguments:   None
// Returns:     None
/* ------------------------------------------------------------------------------------------- */
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

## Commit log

2019-10-15 Updated Eagle PCB
    [LogBoard.brd, LogBoard.sch]
2019-10-15 Updated BOM
    [BOM.xlsx, LogBoard.brd, LogBoard.sch]
2019-10-15 Added PDF schematic
2019-10-15 Added info regarding SPI DIO mode
    [LogBoard.sch]
2019-10-17 Load config from SD card
    [NewConfig_Example.txt]
2019-10-17 Added firmware update via SD card
    [NewConfig_Example.txt]
2019-10-17 Reorganized folder structure
    [NewConfig_Example.txt]
2019-10-19 v1.1 Not finished yet
    [NewConfig_Example.txt]
2019-10-20 Post working. Missing SD card log
    [LogBoard.ino]
2019-10-21 Sync 99%. Missing replace line feature.
    [LogBoard.ino]
2019-10-21 v1.1 done. Missing only LineReplace feature of Sync
    [LogBoard.ino]
2019-10-21 Updated flowchart
2019-10-21 Flowchart rebuilt

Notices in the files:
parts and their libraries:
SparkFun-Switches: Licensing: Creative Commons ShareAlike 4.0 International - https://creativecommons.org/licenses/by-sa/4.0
